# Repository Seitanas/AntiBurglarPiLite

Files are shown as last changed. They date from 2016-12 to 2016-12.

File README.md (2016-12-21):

AntiBurglar-pi Lite  
=====  
  
Home security system, based on raspberry-pi.  
System monitors two security zones, two temperature zones. Uses gnokii to send sms via gsm phone or modem, activates
siren via relay.  
Also monitors status of powerline, reports if power is down.  
System control is done via SMS commands:  
  
<b>arm password</b> (e.g arm 1111) - system is armed instantly.  
<b>disarm password</b> - armed system deactivates after receiving SMS.  
<b>status password</b> - system responds with device uptime and temperature status after receiving SMS.  
<b>siren on password</b> - siren is turned on.  
<b>siren off password</b> - siren is turned off.  
  
When triggered, alarm warning is sent do a predefined number in config.h file.  
  
Edit src/config.h and /boot/abp.conf to fit your needs.  
You need to install libgnokii development libraries, also wiringpi:  
http://wiringpi.com/download-and-install/  
Make sure to create /etc/gnokii.conf config file with configuration for your GSM modem or phone.  
Example of working gnokii.conf file with "Huawei Technologies Co., Ltd. E220 HSDPA Modem / E230/E270/E870 HSDPA/HSUPA" modem:  
  
    [global]
    model = AT
    port = /dev/ttyUSB0
    connection = serial

To build and install system
    make
    make install

If using raspbian distribution, copy init script from debian_init folder  
to /etc/init.d/ folder.  
Start antiburglar-pi with /etc/init.d/abp start

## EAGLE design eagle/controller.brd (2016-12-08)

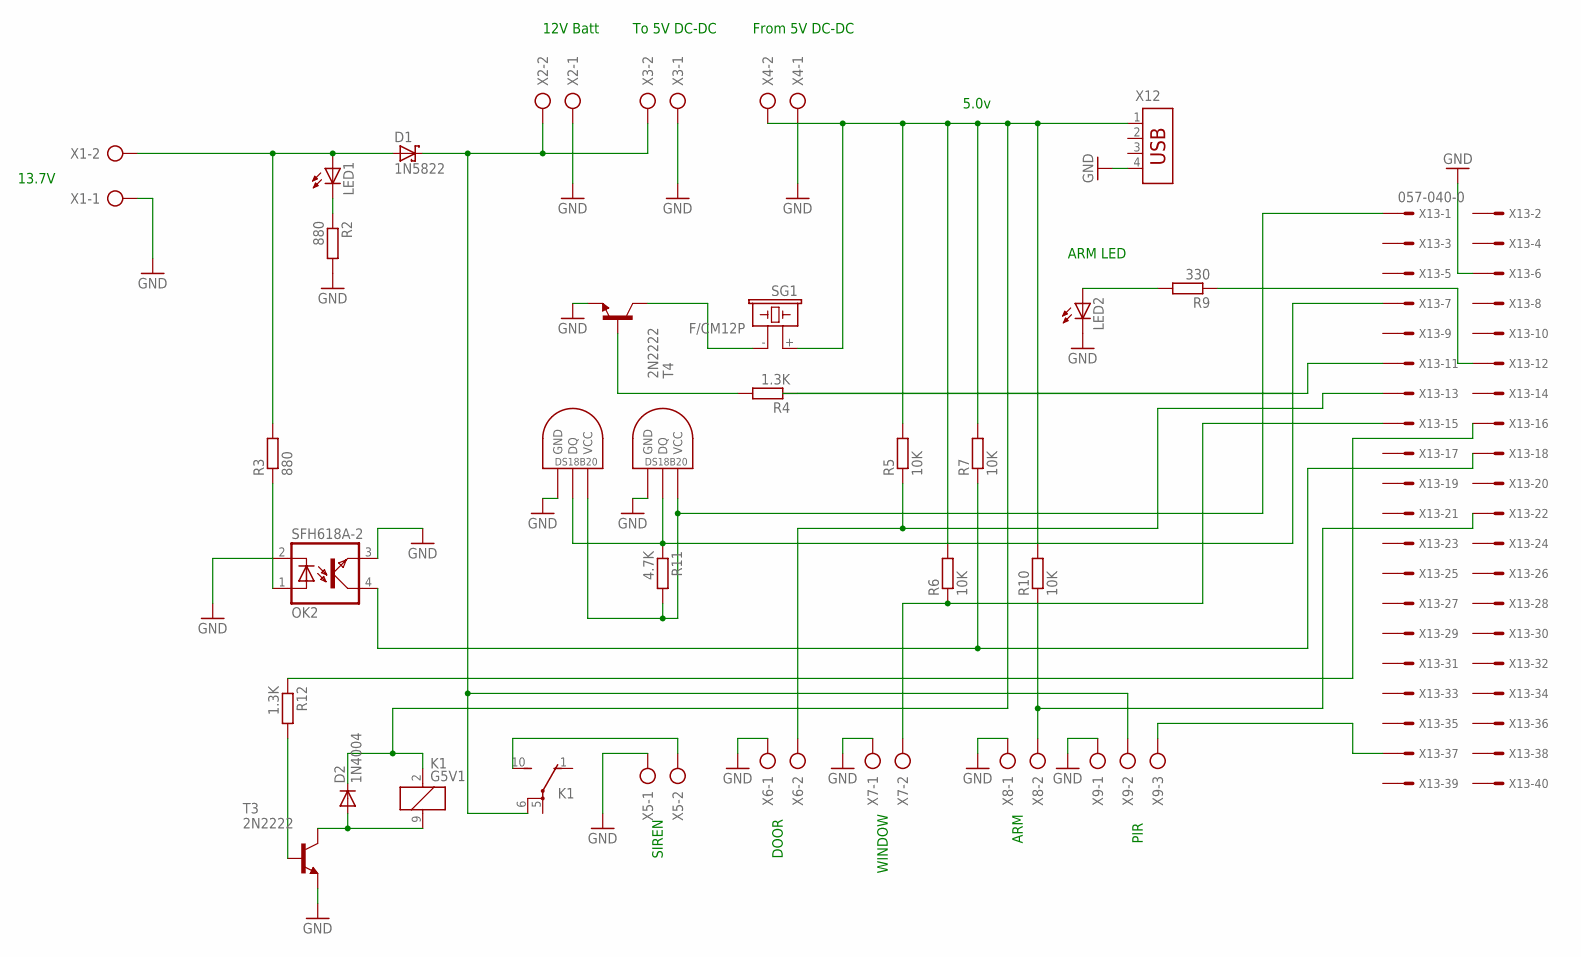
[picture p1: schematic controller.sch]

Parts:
D1: 1N5822; DO201T15
D2: 1N4004; DO41-10
K1: G5V1
LED1, LED2: LED5MM
OK2: SFH618A-2; DIP4
R2, R3: 880; 0204/7
R4, R12: 1.3K; 0204/7
R5, R6, R7, R10: 10K; 0204/7
R9: 330; 0204/7
R11: 4.7K; 0204/7
SG1: F/CM12P
T3, T4: 2N2222; TO92-EBC
U$1, U$2: DS1820TO92; DS1820
X1, X2, X3, X4, X5, X6, X7, X8: AK500/2
X9: AK500/3-H
X12: USB-787616; USB
X13: 057-040-0

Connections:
GND: LED2.K (C), OK2.2 (C), OK2.3 (EMIT), R2.2, T3.E, T4.E, U$1.GND, U$2.GND, X1.1, X2.1, X3.1, X4.1, X5.1, X6.1, X7.1, X8.1, X9.1, X12.4, X13.6
unnamed: D1.A, LED1.A, R3.2, X1.2
unnamed: R12.2, T3.B
unnamed: D2.A, K1.9 (2), T3.C
unnamed: D1.C, K1.6, X2.2, X3.2, X9.2
unnamed: X9.3, X13.37
unnamed: R4.1, X13.11
unnamed: LED1.K (C), R2.1
unnamed: OK2.1 (A), R3.1
unnamed: OK2.4 (COL), R7.1, X13.18
unnamed: R4.2, T4.B
unnamed: SG1.- (2), T4.C
unnamed: R5.1, X6.2, X13.13
unnamed: R6.1, X7.2, X13.15
unnamed: LED2.A, R9.2
unnamed: R9.1, X13.12
unnamed: R10.1, X8.2, X13.22
unnamed: R11.1, U$1.DQ, U$2.DQ, X13.7
unnamed: R11.2, U$1.VDD (VCC), U$2.VDD (VCC), X13.1
unnamed: R12.1, X13.16
unnamed: D2.C, K1.2 (1), R5.2, R6.2, R7.2, R10.2, SG1.+ (1), X4.2, X12.1
unnamed: K1.10 (S), X5.2

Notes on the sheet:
5.0v
DOOR
WINDOW
ARM
ARM LED
13.7V
SIREN
12V Batt
To 5V DC-DC
From 5V DC-DC
PIR

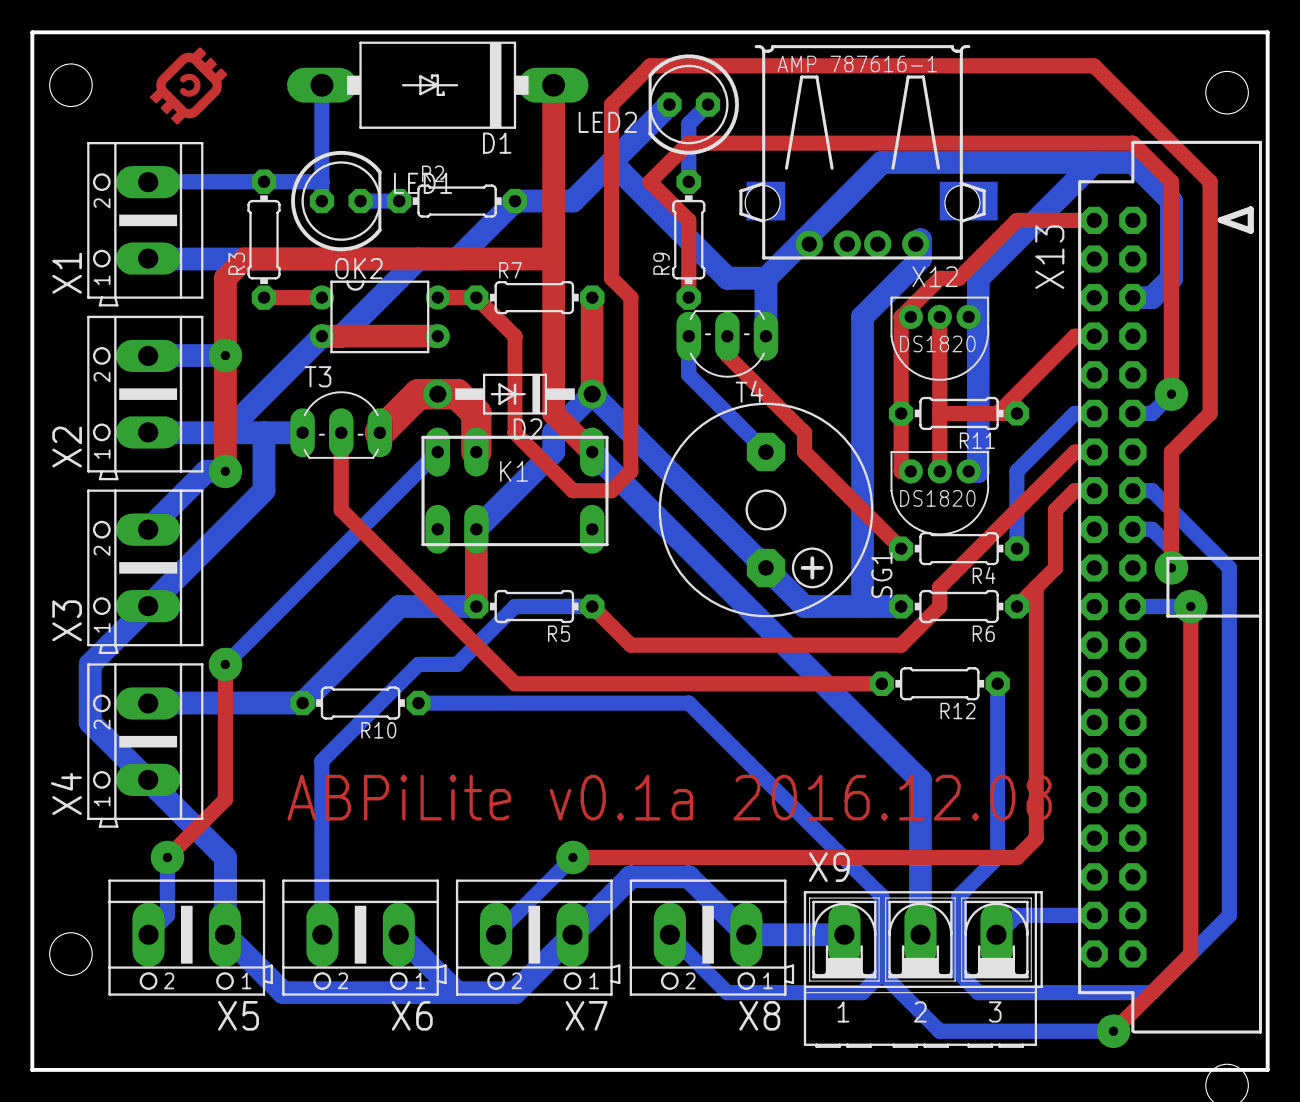
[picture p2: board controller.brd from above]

Board: 2 copper layers, 81.3 x 68.2 mm, 33 parts (0 on the bottom side), 22 nets.

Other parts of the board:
U$3: OPEN_HARDWARE_LOGO

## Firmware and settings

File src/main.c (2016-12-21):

/*
    AntiBurglarPi Lite
    Tadas Ustinavičius
    2016-12-21
*/


#include "sms.h"
#include <stdio.h>
#include <sys/sysinfo.h>
#include <locale.h>
#include "globals.h"
#include <wiringPi.h>
#include <pthread.h>
#include "syslog.h"
#include <stdlib.h>
#include "config.h"
#include <libconfig.h>
int door=0, window=0, pwr=0,arm=0, motion=0, ARMING_SECONDS;
int door_sent=0, window_sent=0, pwr_sent=0, arm_sent=0, motion_sent=0;
char RECIPIENT[64], SENSOR1[64], SENSOR2[64];

void init_gpio(void){
    wiringPiSetup ();    
    pinMode (BUZZER, OUTPUT) ;
    pinMode (ARMED_LED, OUTPUT);
    pinMode(DOOR, INPUT);
    pinMode(WINDOW, INPUT);
    pinMode(POWER, INPUT);
    pinMode(ARM_BUTTON, INPUT);
    pinMode(MOTION, INPUT);
    pinMode(SIREN, OUTPUT);
    digitalWrite (BUZZER, LOW) ;
    digitalWrite (ARMED_LED, LOW) ;
    digitalWrite (SIREN, LOW);
}


void read_sensors(void){ //read all GPIO inputs, except temperature.
    door=digitalRead(DOOR);
    window=digitalRead(WINDOW);
    pwr=digitalRead(POWER);
    arm=digitalRead(ARM_BUTTON);
    motion=digitalRead(MOTION);
}

void * armed_blink(){//blinks LED while system is armed.
    while (armed){
	digitalWrite (ARMED_LED, HIGH) ;
        usleep(200000);
        digitalWrite (ARMED_LED, LOW) ;
	usleep(200000);
    }
    digitalWrite(ARMED_LED,LOW); //reset signal to low
    pthread_exit(0);
}

void arm_beep(void){//beep for period of arming_seconds.
    int x=ARMING_SECONDS*2;
    while (x!=0){
	int pulse=0;
	while (pulse!=100){
	    ++pulse;
	    digitalWrite(BUZZER,HIGH);
	    usleep(650);
	    digitalWrite(BUZZER,LOW);
	    usleep(650);
	}
	usleep(400000);
	--x;
    }
    x=3;
    while (x!=0){//emit 3 short beeps to inform, that system is armed
	int pulse=0;
	while (pulse!=30){
	    ++pulse;
	    digitalWrite(BUZZER,HIGH);
	    usleep(300);
	    digitalWrite(BUZZER,LOW);
	    usleep(300);
	}
	usleep(200000);
	--x;
    }	
    digitalWrite(BUZZER,LOW); //reset signal to low
}

void disarm_beep(){
    int x=4;
    while (x!=0){
	int pulse=0;
	while (pulse!=30){
	    ++pulse;
	    digitalWrite(BUZZER,HIGH);
	    usleep(340);
	    digitalWrite(BUZZER,LOW);
	    usleep(300);
	}
	usleep(200000);
	--x;
    }	
    digitalWrite(BUZZER,LOW); //reset signal to low
}
int read_temp(char *device_path){
    FILE *fp;
    char tmp[80],tmp2[80];
    char junk[80],crc[5],crc2[5];
    int value=0;
    if ((fp = fopen(device_path,"r")) != (FILE *)NULL) {
	fgets(tmp,80,fp); /* Get first line w/ checksums */
        fgets(tmp2,80,fp); /* Get 2nd line w/ temp */
	sscanf(tmp,"%[^:]: %[^ ] %s\n",junk,crc,crc2);
        sscanf(tmp2,"%[^=]=%d\n",junk,&value);
	fclose(fp);
    }
    else {
	char tmp[64];
	sprintf(tmp,"SENSOR on %s was not found",device_path);
	syslog_write(tmp);
    }
    return value;
}
void daemon(){
        pid_t mypid;
        FILE *pid;
        mypid=fork();
        if (mypid){
                pid=fopen("/var/run/abp/abp.pid","w");
                fprintf(pid,"%i",mypid);
                exit (0);
        }
}
void system_exit(void){
    syslog_write("Stopping antiburglar-pi");
}
void call_led_thread(void){
    pthread_t tid;
    pthread_create(&tid,NULL,armed_blink,NULL);
    pthread_detach(tid);
}

int read_config(){
    config_t cfg;
    config_init(&cfg);
    if (!config_read_file(&cfg,"/boot/abp.conf")) {
        fprintf(stderr, "%s:%d - %s\n",
            config_error_file(&cfg),
            config_error_line(&cfg),
            config_error_text(&cfg));
        syslog_write("Missing /boot/abp.conf file");
	config_destroy(&cfg);
        return(EXIT_FAILURE);
    }
    const char *password = NULL;
    const char *phone = NULL;
    const char *s1 = NULL;
    const char *s2 = NULL;
    int as;
    if (config_lookup_string(&cfg, "password", &password))
       sprintf(PASSWORD,password);
    if (config_lookup_string(&cfg, "master_number", &phone))
	sprintf(RECIPIENT,phone);
    if (config_lookup_string(&cfg, "sensor1", &s1))
       sprintf(SENSOR1,s1);
    if (config_lookup_string(&cfg, "sensor2", &s2))
       sprintf(SENSOR2,s2);
    if (config_lookup_int(&cfg, "arm_seconds", &as))
	ARMING_SECONDS=as;
    config_destroy(&cfg);
    return 0;
}

int main (void){
    exit;
    atexit (system_exit);
    syslog_write("Starting antiburglar-pi");
    if (read_config())
	exit(EXIT_FAILURE);
    init_gpio();
    disarm_beep(); //beep at system startup
//    daemon();
    setlocale(LC_ALL, "");
    sleep (1); //wait for dust to settle
    armed=0;
    char temp_message[200];
    int door_sent=0, window_sent=0, power_sent=0;
    int timer=0;
    while (1){//main loop
        read_sensors();
	++timer;
        if (!armed&&!arm){//arm button pressed. gpio pin low
            arm_beep();
            read_sensors();
	    armed=1;
	    gnokii_send(RECIPIENT,"System armed.");
	    syslog_write("System armed.");
	    call_led_thread();
        }
	if (armed&&door&&!door_sent){//system is armed, door was opened, sms was not sent
	    gnokii_send(RECIPIENT,"Door is open, triggering alarm.");
	    digitalWrite(SIREN,HIGH);
	    door_sent=1;
	    syslog_write("Door is open, triggering alarm.");
	}
	if (armed&&window&&!window_sent){//system is armed, window was opened, sms was not sent
	    gnokii_send(RECIPIENT,"Window is open, triggering alarm");
	    digitalWrite(SIREN,HIGH);
	    window_sent=1;
	    syslog_write("Window is open, triggering alarm");
	}
	if (armed&&motion&&!motion_sent){//system is armed, motion was detected, sms was not sent
	    gnokii_send(RECIPIENT,"Motion detected, triggering alarm");
	    digitalWrite(SIREN,HIGH);
	    motion_sent=1;
	    syslog_write("Window is open, triggering alarm");
	}

	if (pwr&&!power_sent){
	    power_sent=1;
	    gnokii_send(RECIPIENT,"Power loss detected");
	    syslog_write("Power loss detected");
	}
	if (!pwr&&power_sent){
	    power_sent=0;
	    gnokii_send(RECIPIENT,"Power is back to normal");
	    syslog_write("Power is back to normal");
	}
	if (timer==300){//check inbox every minute 
    	    getsms();
    	    timer=0;
	}
        if (send_status){
	    float temp1=0,temp2=0;
	    temp1=read_temp(SENSOR1);
	    temp2=read_temp(SENSOR2);
    	    send_status=0;
    	    struct sysinfo info;
    	    sysinfo(&info);
	    int days = info.uptime / (60 * 60 * 24);
	    info.uptime -= days * (60 * 60 * 24);
	    int hours = info.uptime / (60 * 60);
	    info.uptime -= hours * (60 * 60);
	    int minutes = info.uptime / 60;
	    info.uptime -= minutes * 60;
	    char uptime[160];
	    char window_status[10];
	    char door_status[10];
	    char arm_status[10];
	    char siren_status[10];
	    char motion_status[10];
	    if (motion)
		sprintf(motion_status,"yes. ");
	    else
		sprintf(motion_status,"no. ");
	    if (window)
		sprintf(window_status,"open. ");
	    else
		sprintf(window_status,"closed. ");
	    if (door)
		sprintf(door_status,"open. ");
	    else
		sprintf(door_status,"closed. ");
	    if (digitalRead(SIREN))
	    	sprintf(siren_status,"on. ");
	    else
		sprintf(siren_status,"off. ");
	    if (armed)
		sprintf(arm_status,"armed.");
	    else
		sprintf(arm_status,"disarmed.");
    	    sprintf(uptime,"UP: %i days, %i hours, %i minutes, %i seconds. Load average: %.2f %.2f %.2f Temp1: %.2f Temp2: %.2f. Window: %sDoor: %s Motion detected: %s Siren: %sSystem: %s",days,hours,minutes, info.uptime,info.loads[0]/65536.0, info.loads[1]/65536.0, info.loads[2]/65536.0,temp1/1000,temp2/1000,window_status,door_status,motion_status,siren_status,arm_status);
	    sprintf(temp_message,"Client %s is requesting status.",sms_sender);	    
	    syslog_write(temp_message);
	    gnokii_send(sms_sender,uptime);
	}
	if (disarm){
	    disarm=0;
	    armed=0;
	    motion=0;
	    door_sent=0;
	    window_sent=0;
	    motion_sent=0;
	    power_sent=0;
	    digitalWrite(SIREN,LOW);
	    syslog_write("System disarmed");
	    gnokii_send(sms_sender,"System disarmed");
	    disarm_beep();
	}
    usleep (200000);
    }
}

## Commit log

2016-11-11 First PCB
    [controller.brd, controller.sch]
2016-11-12 Updating PIR
    [controller.brd, controller.sch]
2016-11-12 First production release
    [controller.brd]
2016-11-30 Fixing schematic bug
    [controller.brd, controller.sch]
2016-12-01 Small redesign. Bugfixes
    [controller.brd, controller.sch]
2016-12-01 Board update
    [controller.brd, controller.sch]
2016-12-08 Optimising board
    [controller.brd]
